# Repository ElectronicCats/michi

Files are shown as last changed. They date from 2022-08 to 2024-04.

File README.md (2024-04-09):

# Michi

<a href="https://electroniccats.com/store/michi/">
  
</a>

<a href="https://github.com/ElectronicCats/michi/wiki">
  
</a>
</p>

  Michi is an electronic board designed by Electronic Cats that simulates configurable keyboard and mouse keys. It has the feature of being able to connect to any conductive material, turning these objects into touch panels. 

  It is an experiment kit for beginners and experts looking to interact between the real world and technology. The Michi can cover the areas of plastic arts, visual arts, music, sports, engineering and even physical rehabilitation.

## For whom is Michi? 

  People 6 years and older, educators, artists, engineers, designers, inventors and creators. 

## How does it work?

  The Michi uses high resistance switching to detect when it has made a connection even with materials that are not very conductive (such as leaves, pasta or people). This technique attracts, Michi can also act as a keyboard or mouse. There are 10 inputs on the front of the board, which can be linked via alligator wires or any other method you can think of. There are another 5 inputs on the back, 3 for keyboard keys and 2 for mouse movement, which can be accessed with jumpers.

  For example, when you connect and touch an apple, you make a connection, and Michi sends the computer a keyboard message. The computer sees Michi as an ordinary keyboard (or mouse). Therefore, it works with all programs, operating systems and web pages, since all programs and web pages receive information from the keyboard and mouse.

## What materials work with Michi?

  Any material that can conduct a little electricity will work. Here are some materials that people have used in our workshops: Ketchup or tomato sauce, Pencil Graphite, Finger Paint, Lemons, etc.

  Other materials that work very well: plants, coins, silverware, anything wet, most foods, aluminum foil, water, and hundreds of things we haven't tried.

## What can I do?

  That's up to you! First, load a computer program or any web page. Let's say you load a piano. Then, instead of using the buttons on the computer keyboard to play the piano, you can connect Michi to something fun, like bananas, and the bananas become your piano keys. 

  Or let's say you search for a Pacman game online and draw a joystick with a pencil. Then you can play Pacman by touching the drawing. 
  The kit includes everything you need: Michi Board, alligator cable, USB cable.

## Manual

Visit our Wiki where you can find the manual 📖: [Wiki](https://github.com/ElectronicCats/michi/wiki)

michi-removebg-preview (https://github.com/ElectronicCats/michi/wiki)

## How to contribute 
 Contributions are welcome! 

Please read the document  [**Contribution Manual**](https://github.com/ElectronicCats/electroniccats-cla/blob/main/electroniccats-contribution-manual.md)  which will show you how to contribute your changes to the project.

✨ Thanks to all our [contributors](https://github.com/ElectronicCats/michi/graphs/contributors)! ✨

See  [**_Electronic Cats CLA_**](https://github.com/ElectronicCats/electroniccats-cla/blob/main/electroniccats-cla.md) for more information.

See the [**community code of conduct**](https://github.com/ElectronicCats/electroniccats-cla/blob/main/electroniccats-community-code-of-conduct.md)   for a vision of the community we want to build and what we expect from it.

### Maintainer

Electronic Cats invests time and resources in providing this open-source design design, please support Electronic Cats and open-source hardware by purchasing products from Electronic Cats!

<a href="https://github.com/sponsors/ElectronicCats">
  
</a>

## Licence

Firmware released under an GNU AGPL v3.0 license. See the [LICENSE](https://www.gnu.org/licenses/agpl-3.0.en.html) file for more information.

Hardware released under an CERN Open Hardware Licence v1.2. See the [LICENSE_HARDWARE](https://ohwr.org/project/licences/wikis/cern-ohl-v1.2) file for more information.

Electronic Cats is a registered trademark, please do not use if you sell these PCBs.

Electronic Cats invests time and resources providing this open source design, please support Electronic Cats and open-source hardware by purchasing products from Electronic Cats!

Designed by Electronic Cats.

30 Jul 2022

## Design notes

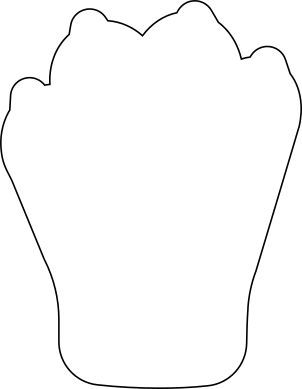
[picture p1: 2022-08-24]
Art/PCB_Michi_Act.png

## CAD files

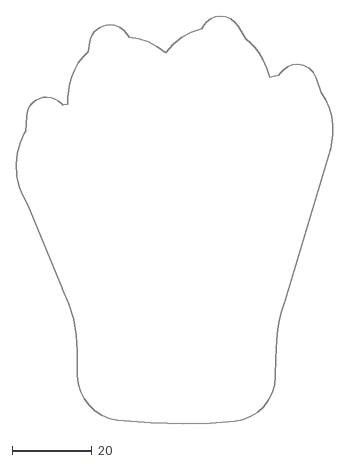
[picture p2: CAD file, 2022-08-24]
Art/PCB_Michi_Act.dxf
79.5 x 102.4

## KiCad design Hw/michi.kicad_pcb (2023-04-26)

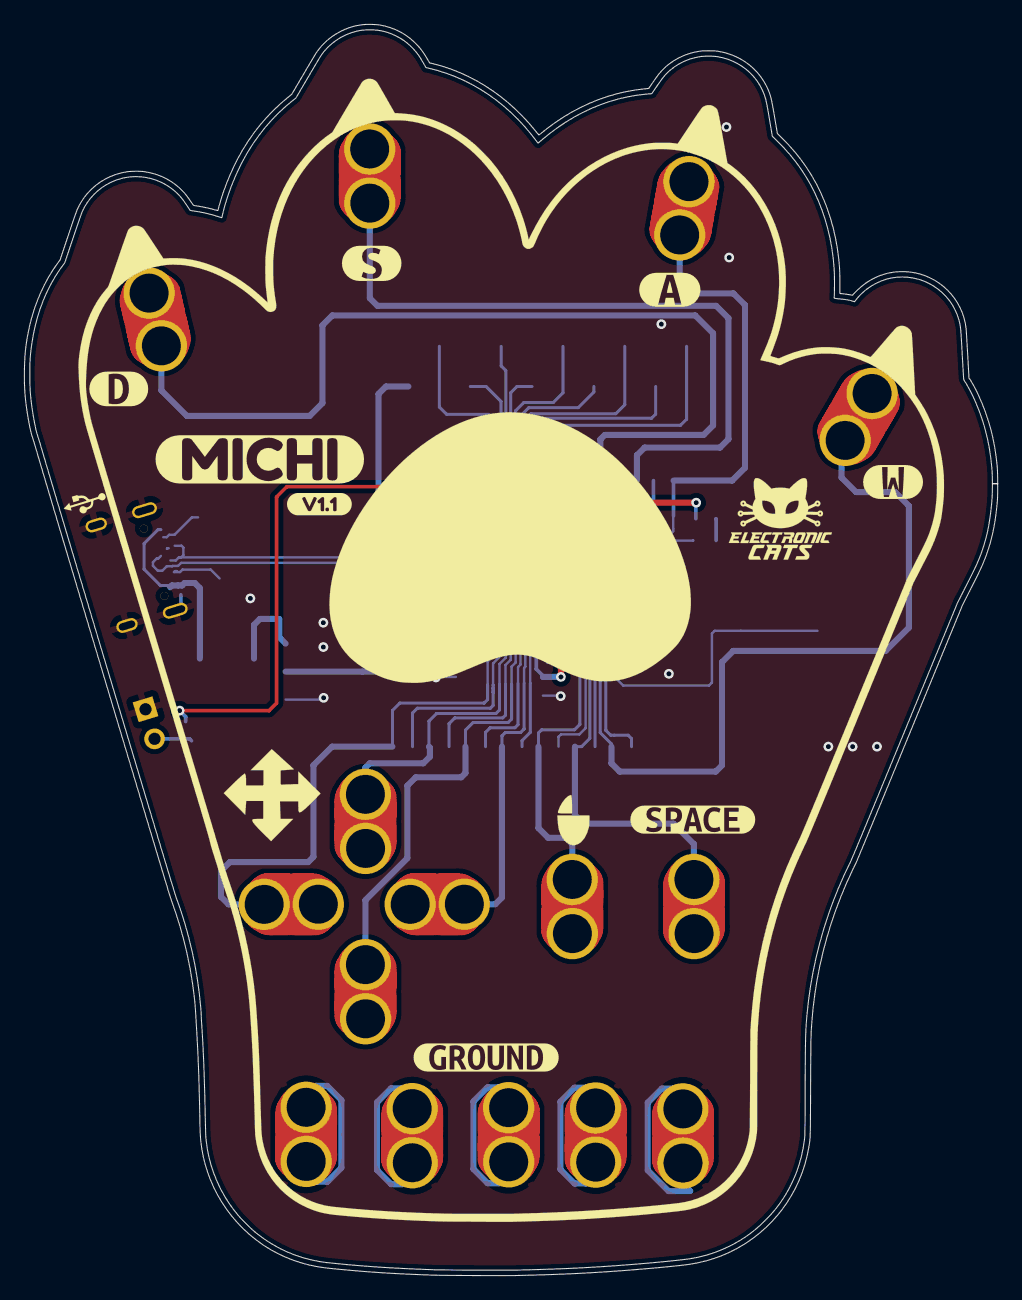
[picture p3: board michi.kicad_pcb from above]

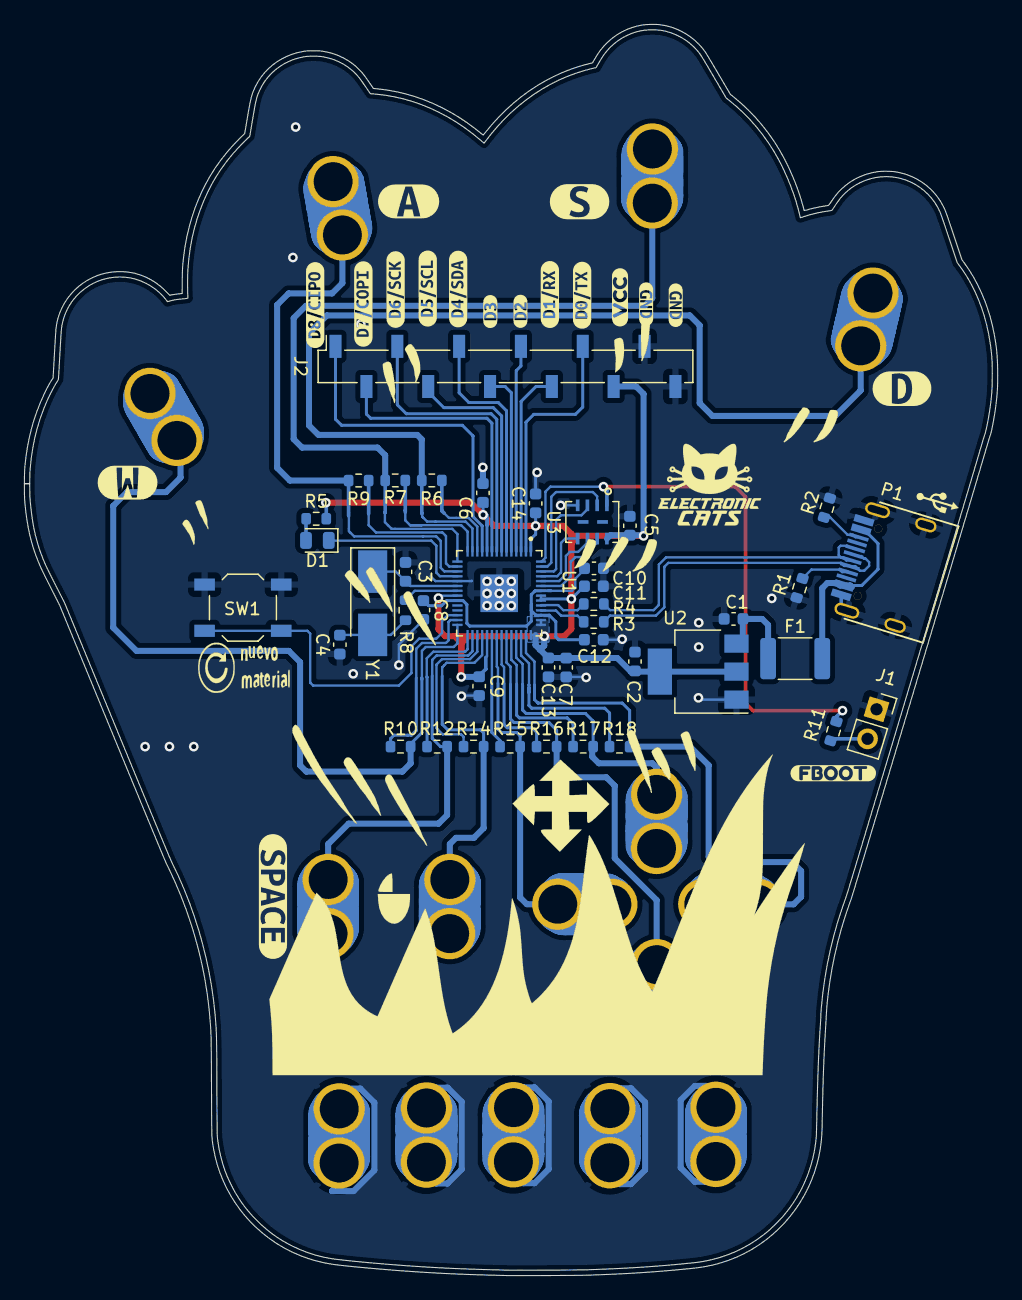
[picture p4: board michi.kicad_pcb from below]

Board: 2 copper layers, 80.0 x 102.8 mm, 85 parts (61 on the bottom side), 53 nets.

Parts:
C1, C2: 10uf; C_0603_1608Metric
C3, C4: 27pf; C_0603_1608Metric
C5, C7, C9, C10, C11, C12, C13, C14: .1uf; C_0603_1608Metric
C6, C8: 1uf; C_0603_1608Metric
D1: LED; D_0805_2012Metric
F1: 0.5A; Fuse_1812_4532Metric_Pad1.30x3.40mm_HandSolder
J1: Conn_01x02; PinSocket_1x02_P2.54mm_Vertical
J2: Conn_Right; PinSocket_1x12_P2.54mm_Vertical_SMD_Pin1Right
P1: USB_C_Plug_USB2.0; C393939
P6, P6#2, P6#3, P6#4, P6#5, P6#6, P6#7, P6#8, P6#9, P6#10, P6#11, P6#12, P6#13, P6#14, P6#15: D; SEWALLI_renew
R1, R2: 5.1K; R_0603_1608Metric
R3, R4: 27.4; R_0603_1608Metric
R5, R8, R11: 1k; R_0603_1608Metric
R6, R7, R9, R10, R12, R14, R15, R16, R17, R18: 22M; R_0603_1608Metric
Ref**: Val**; PCB_Michi_Act
SW1: SW_Push; SW_SPST_TL3342
U1: RP2040; QFN40P700X700X90-57N
U2: NCP1117ST33T3G; SOT-223-3_TabPin2
U3: W25Q128JVS; W25Q16JVUUIQ
Y1: Crystal; Crystal_SMD_5032-2Pin_5.0x3.2mm_HandSoldering
kibuzzard-63055E6D, kibuzzard-63055E6D#2: G***; kibuzzard-63055E6D
kibuzzard-63055E8E, kibuzzard-63055E8E#2: G***; kibuzzard-63055E8E
kibuzzard-63055E62, kibuzzard-63055E62#2: G***; kibuzzard-63055E62
kibuzzard-63055EA5, kibuzzard-63055EA5#2: G***; kibuzzard-63055EA5
kibuzzard-63055F28: G***; kibuzzard-63055F28
kibuzzard-63055FE6, kibuzzard-63055FE6#2: G***; kibuzzard-63055FE6
kibuzzard-630561F0: G***; kibuzzard-630561F0
kibuzzard-630562A3, kibuzzard-630562A3#2: G***; kibuzzard-630562A3
kibuzzard-630562BF: G***; kibuzzard-630562BF
kibuzzard-639765AD: G***; kibuzzard-639765AD
kibuzzard-639765C9: G***; kibuzzard-639765C9
kibuzzard-6305622D: G***; kibuzzard-6305622D
kibuzzard-6305624B: G***; kibuzzard-6305624B
kibuzzard-6305640E: G***; kibuzzard-6305640E
kibuzzard-6449595B: G***; kibuzzard-6449595B
kibuzzard-63056210: G***; kibuzzard-63056210
kibuzzard-63056260: G***; kibuzzard-63056260
kibuzzard-63056270: G***; kibuzzard-63056270
kibuzzard-63056280: G***; kibuzzard-63056280
kibuzzard-63056299: G***; kibuzzard-63056299
svg2mod, svg2mod#2: G***; usb_graphic

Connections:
+1V1: C8.1, C10.1, C12.1, U1.23 (DVDD), U1.45 (VREG_VOUT), U1.50 (DVDD)
+3V3: C2.1, C5.1, C6.1, C7.1, C9.1, C11.1, C13.1, C14.1, J2.10, R5.2, U1.1 (IOVDD), U1.10 (IOVDD), U1.22 (IOVDD), U1.33 (IOVDD), U1.42 (IOVDD), U1.43 (ADC_AVDD), U1.44 (VREG_VIN), U1.48 (USB_VDD), U1.49 (IOVDD), U2.2 (VO), U3.8 (VCC)
/D+: P1.A6 (D+), R4.2
/D-: P1.A7 (D-), R3.2
/DR+: R4.1, U1.47 (USB_DP)
/DR-: R3.1, U1.46 (USB_DM)
/IO0: J2.9, U1.2 (GPIO0)
/IO1: J2.8, U1.3 (GPIO1)
/IO2: J2.7, U1.4 (GPIO2)
/IO3: J2.6, U1.5 (GPIO3)
/IO4: J2.5, U1.6 (GPIO4)
/IO5: J2.4, U1.7 (GPIO5)
/IO6: J2.3, U1.8 (GPIO6)
/IO7: J2.2, U1.9 (GPIO7)
/IO8: J2.1, U1.11 (GPIO8)
/IO9: R6.2, U1.12 (GPIO9)
/IO10: P6#10.1, R6.1, U1.13 (GPIO10)
/IO11: R7.2, U1.14 (GPIO11)
/IO12: P6#12.1, R7.1, U1.15 (GPIO12)
/IO13: R9.2, U1.16 (GPIO13)
/IO14: P6.1, R9.1, U1.17 (GPIO14)
/IO15: D1.1 (K), U1.18 (GPIO15)
/IO16: R10.2, U1.27 (GPIO16)
/IO17: P6#11.1, R10.1, U1.28 (GPIO17)
/IO18: R12.2, U1.29 (GPIO18)
/IO19: P6#15.1, R12.1, U1.30 (GPIO19)
/IO20: R14.2, U1.31 (GPIO20)
/IO21: P6#8.1, R14.1, U1.32 (GPIO21)
/IO22: R15.2, U1.34 (GPIO22)
/IO23: P6#6.1, R15.1, U1.35 (GPIO23)
/IO24: R16.2, U1.36 (GPIO24)
/IO25: P6#2.1, R16.1, U1.37 (GPIO25)
/IO26: R17.2, U1.38 (GPIO26/ADC0)
/IO27: P6#3.1, R17.1, U1.39 (GPIO27/ADC1)
/IO28: R18.2, U1.40 (GPIO28/ADC2)
/IO29: P6#7.1, R18.1, U1.41 (GPIO29/ADC3)
/RST: SW1.1, U1.26 (RUN)
/SCLK: U1.52 (QSPI_SCLK), U3.6 (CLK)
/SD1: U1.55 (QSPI_SD1), U3.2 (DO(IO1))
/SD2: U1.54 (QSPI_SD2), U3.3 (IO2)
/SD3: U1.51 (QSPI_SD3), U3.7 (IO3)
/SDO: U1.53 (QSPI_SD0), U3.5 (DI(IO0))
/SS: R11.2, U1.56 (QSPI_CSN), U3.1 (~CS)
/XIN: C3.2, U1.20 (XIN), Y1.1
/XOUT: R8.1, U1.21 (XOUT)
GND: C1.2, C2.2, C3.1, C4.1, C5.2, C6.2, C7.2, C8.2, C9.2, C10.2, C11.2, C12.2, C13.2, C14.2, J1.1, J2.11, J2.12, P1.A1 (GND), P1.S1 (SHIELD), P6#4.1, P6#5.1, P6#9.1, P6#13.1, P6#14.1, R1.2, R2.2, SW1.2, U1.19 (TESTEN), U1.57 (GND), U2.1 (GND), U3.4 (GND)
unnamed: C4.2, R8.2, Y1.2
unnamed: D1.2 (A), R5.1
unnamed: F1.2, P1.A4 (VBUS)
unnamed: J1.2, R11.1
unnamed: P1.A5 (CC), R1.1
unnamed: P1.B5 (VCONN), R2.1
VBUS: C1.1, F1.1, U2.3 (VI)

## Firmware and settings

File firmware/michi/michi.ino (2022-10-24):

/*
 /////////////////////////////////////////////////
 /////////////HOW TO EDIT THE KEYS ///////////////
 /////////////////////////////////////////////////
 - Edit keys in the settings.h file
 - that file should be open in a tab above (in Arduino IDE)
 - more instructions are in that file
 
 //////////////////////////////////////////////////
 ///////// MICHI FIRMWARE v1.0.0 ////////////
 //////////////////////////////////////////////////


 /************************************************************
Michi - Using the Michi you can make anything into a key 
just by connecting a few alligator clips

Andres Sabas @ Electronic Cats
Original Creation Date: Sept 6, 2022
https://github.com/ElectronicCats/MeowMeow

This example demonstrates how to use Meow Meow

Development environment specifics:
  IDE: Arduino 1.8.19
  Hardware Platform:
  Michi
  - RP2040

This code is beerware; if you see me (or any other Electronic Cats 
member) at the local, and you've found our code helpful, 
please buy us a round!

Distributed as-is; no warranty is given.

Based in the work by:
 by: Eric Rosenbaum, Jay Silver, and Jim Lindblom
 MIT Media Lab & Sparkfun
 start date: 2/16/2012 
 release: 7/5/2012
 ***************************************************************************/

/////////////////////////
// DEBUG DEFINITIONS ////               
/////////////////////////
//#define DEBUG
//#define DEBUG2 
//#define DEBUG3 
//#define DEBUG_TIMING
//#define DEBUG_MOUSE
//#define DEBUG_TIMING2

////////////////////////
// DEFINED CONSTANTS////
////////////////////////

#define BUFFER_LENGTH    3     // 3 bytes gives us 24 samples
#define NUM_INPUTS       10    // 6 on the front + 12 on the back
#define NUM_OUTPUTS       10    //
//#define TARGET_LOOP_TIME 694   // (1/60 seconds) / 24 samples = 694 microseconds per sample 
//#define TARGET_LOOP_TIME 758  // (1/55 seconds) / 24 samples = 758 microseconds per sample 
#define TARGET_LOOP_TIME 744  // (1/56 seconds) / 24 samples = 744 microseconds per sample 

// id numbers for mouse movement inputs (used in settings.h)
#define MOUSE_MOVE_UP       -1 
#define MOUSE_MOVE_DOWN     -2
#define MOUSE_MOVE_LEFT     -3
#define MOUSE_MOVE_RIGHT    -4

#include <Keyboard.h>
#include <Mouse.h>
#include "settings.h"

/////////////////////////
// STRUCT ///////////////
/////////////////////////
typedef struct {
  byte pinNumber;
  int keyCode;
  byte measurementBuffer[BUFFER_LENGTH]; 
  boolean oldestMeasurement;
  byte bufferSum;
  boolean pressed;
  boolean prevPressed;
  boolean isMouseMotion;
  boolean isMouseButton;
  boolean isKey;
} 
MakeyMakeyInput;

MakeyMakeyInput inputs[NUM_INPUTS];

///////////////////////////////////
// VARIABLES //////////////////////
///////////////////////////////////
int bufferIndex = 0;
byte byteCounter = 0;
byte bitCounter = 0;
int mouseMovementCounter = 0; // for sending mouse movement events at a slower interval

int pressThreshold;
int releaseThreshold;
boolean inputChanged;

int mouseHoldCount[NUM_INPUTS]; // used to store mouse movement hold data

// Pin Numbers
// input pin numbers for kickstarter production board
int pinNumbers[NUM_INPUTS] = {
  27, 25, 29, 23, 19, 21,     // top of makey makey board
  17, 14, 12, 10        // left side of female header, KEYBOARD
     // right side of female header, MOUSE
};

int pinNumbers2[NUM_OUTPUTS] = {
  9, 11, 13, 16, 18, 20,     // top of makey makey board
  22, 24, 26, 28        // left side of female header, KEYBOARD
     // right side of female header, MOUSE
};

// input status LED pin numbers
const int inputLED_a = 15;
const int inputLED_b = 8;
const int inputLED_c = 7;
const int outputK = 0;
const int outputM = 1;
byte ledCycleCounter = 0;

// timing
int loopTime = 0;
int prevTime = 0;
int loopCounter = 0;


///////////////////////////
// FUNCTIONS //////////////
///////////////////////////
void initializeArduino();
void initializeInputs();
void updateMeasurementBuffers();
void updateBufferSums();
void updateBufferIndex();
void updateInputStates();
void sendMouseButtonEvents();
void sendMouseMovementEvents();
void addDelay();
void cycleLEDs();
void danceLeds();
void updateOutLEDs();

//////////////////////
// SETUP /////////////
//////////////////////
void setup() 
{
  initializeArduino();
  initializeInputs();
  danceLeds();
}

////////////////////
// MAIN LOOP ///////
////////////////////
void loop() 
{
  updateMeasurementBuffers();
  updateBufferSums();
  updateBufferIndex();
  updateInputStates();
  sendMouseButtonEvents();
  sendMouseMovementEvents();
  cycleLEDs();
  updateOutLEDs();
  addDelay();
}

//////////////////////////
// INITIALIZE ARDUINO
//////////////////////////
void initializeArduino() {
#ifdef DEBUG
  Serial.begin(9600);  // Serial for debugging
#endif

  /* Set up input pins 
   DEactivate the internal pull-ups, since we're using external resistors */
  for (int i=0; i<NUM_INPUTS; i++)
  {
    pinMode(pinNumbers[i], INPUT);
    digitalWrite(pinNumbers[i], LOW);
  }

  for (int i=0; i<NUM_OUTPUTS; i++)
  {
    pinMode(pinNumbers2[i], OUTPUT);
    digitalWrite(pinNumbers2[i], HIGH);
  }

  pinMode(inputLED_a, INPUT);
  pinMode(inputLED_b, INPUT);
  pinMode(inputLED_c, INPUT);
  digitalWrite(inputLED_a, LOW);
  digitalWrite(inputLED_b, LOW);
  digitalWrite(inputLED_c, LOW);

  pinMode(outputK, OUTPUT);
  pinMode(outputM, OUTPUT);
  digitalWrite(outputK, LOW);
  digitalWrite(outputM, LOW);


#ifdef DEBUG
  delay(4000); // allow us time to reprogram in case things are freaking out
#endif

  Keyboard.begin();
  Mouse.begin();
}

///////////////////////////
// INITIALIZE INPUTS
///////////////////////////
void initializeInputs() {

  float thresholdPerc = SWITCH_THRESHOLD_OFFSET_PERC;
  float thresholdCenterBias = SWITCH_THRESHOLD_CENTER_BIAS/50.0;
  float pressThresholdAmount = (BUFFER_LENGTH * 8) * (thresholdPerc / 100.0);
  float thresholdCenter = ( (BUFFER_LENGTH * 8) / 2.0 ) * (thresholdCenterBias);
  pressThreshold = int(thresholdCenter + pressThresholdAmount);
  releaseThreshold = int(thresholdCenter - pressThresholdAmount);

#ifdef DEBUG
  Serial.println(pressThreshold);
  Serial.println(releaseThreshold);
#endif

  for (int i=0; i<NUM_INPUTS; i++) {
    inputs[i].pinNumber = pinNumbers[i];
    inputs[i].keyCode = keyCodes[i];

    for (int j=0; j<BUFFER_LENGTH; j++) {
      inputs[i].measurementBuffer[j] = 0;
    }
    inputs[i].oldestMeasurement = 0;
    inputs[i].bufferSum = 0;

    inputs[i].pressed = false;
    inputs[i].prevPressed = false;

    inputs[i].isMouseMotion = false;
    inputs[i].isMouseButton = false;
    inputs[i].isKey = false;

    if (inputs[i].keyCode < 0) {
#ifdef DEBUG_MOUSE
      Serial.println("GOT IT");  
#endif

      inputs[i].isMouseMotion = true;
    } 
    else if ((inputs[i].keyCode == MOUSE_LEFT) || (inputs[i].keyCode == MOUSE_RIGHT)) {
      inputs[i].isMouseButton = true;
    } 
    else {
      inputs[i].isKey = true;
    }
#ifdef DEBUG
    Serial.println(i);
#endif

  }
}


//////////////////////////////
// UPDATE MEASUREMENT BUFFERS
//////////////////////////////
void updateMeasurementBuffers() {

  for (int i=0; i<NUM_INPUTS; i++) {

    // store the oldest measurement, which is the one at the current index,
    // before we update it to the new one 
    // we use oldest measurement in updateBufferSums
    byte currentByte = inputs[i].measurementBuffer[byteCounter];
    inputs[i].oldestMeasurement = (currentByte >> bitCounter) & 0x01; 

    // make the new measurement
    boolean newMeasurement = digitalRead(inputs[i].pinNumber);

    // invert so that true means the switch is closed
    newMeasurement = !newMeasurement; 

    // store it    
    if (newMeasurement) {
      currentByte |= (1<<bitCounter);
    } 
    else {
      currentByte &= ~(1<<bitCounter);
    }
    inputs[i].measurementBuffer[byteCounter] = currentByte;
  }
}

///////////////////////////
// UPDATE BUFFER SUMS
///////////////////////////
void updateBufferSums() {

  // the bufferSum is a running tally of the entire measurementBuffer
  // add the new measurement and subtract the old one

  for (int i=0; i<NUM_INPUTS; i++) {
    byte currentByte = inputs[i].measurementBuffer[byteCounter];
    boolean currentMeasurement = (currentByte >> bitCounter) & 0x01; 
    if (currentMeasurement) {
      inputs[i].bufferSum++;
    }
    if (inputs[i].oldestMeasurement) {
      inputs[i].bufferSum--;
    }
  }  
}

///////////////////////////
// UPDATE BUFFER INDEX
///////////////////////////
void updateBufferIndex() {
  bitCounter++;
  if (bitCounter == 8) {
    bitCounter = 0;
    byteCounter++;
    if (byteCounter == BUFFER_LENGTH) {
      byteCounter = 0;
    }
  }
}

///////////////////////////
// UPDATE INPUT STATES
///////////////////////////
void updateInputStates() {
  inputChanged = false;
  for (int i=0; i<NUM_INPUTS; i++) {
    inputs[i].prevPressed = inputs[i].pressed; // store previous pressed state (only used for mouse buttons)
    if (inputs[i].pressed) {
      if (inputs[i].bufferSum < releaseThreshold) {  
        inputChanged = true;
        inputs[i].pressed = false;
        if (inputs[i].isKey) {
          Keyboard.release(inputs[i].keyCode);
        }
        if (inputs[i].isMouseMotion) {  
          mouseHoldCount[i] = 0;  // input becomes released, reset mouse hold
        }
      }
      else if (inputs[i].isMouseMotion) {  
        mouseHoldCount[i]++; // input remains pressed, increment mouse hold
      }
    } 
    else if (!inputs[i].pressed) {
      if (inputs[i].bufferSum > pressThreshold) {  // input becomes pressed
        inputChanged = true;
        inputs[i].pressed = true; 
        if (inputs[i].isKey) {
          Keyboard.press(inputs[i].keyCode);
        }
      }
    }
  }
#ifdef DEBUG3
  if (inputChanged) {
    Serial.println("change");
  }
#endif
}

/*
///////////////////////////
 // SEND KEY EVENTS (obsolete, used in versions with pro micro bootloader)
 ///////////////////////////
 void sendKeyEvents() {
 if (inputChanged) {
 KeyReport report = {
 0                                                        };
 for (int i=0; i<6; i++) {
 report.keys[i] = 0;
 } 
 int count = 0;
 for (int i=0; i<NUM_INPUTS; i++) {
 if (inputs[i].pressed && (count < 6)) {
 report.keys[count] = inputs[i].keyCode;
 
 #ifdef DEBUG3
 Serial.println(report.keys[count]);
 #endif
 
 count++;        
 }
 }
 if (count > 0) {
 report.modifiers = 0x00;
 report.reserved = 1;
 Keyboard.sendReport(&report);
 } 
 else {
 report.modifiers = 0x00;
 report.reserved = 0;
 Keyboard.sendReport(&report);
 }      
 } 
 else {
 // might need a delay here to compensate for the time it takes to send keyreport
 }
 }
 */

/////////////////////////////
// SEND MOUSE BUTTON EVENTS 
/////////////////////////////
void sendMouseButtonEvents() {
  if (inputChanged) {
    for (int i=0; i<NUM_INPUTS; i++) {
      if (inputs[i].isMouseButton) {
        if (inputs[i].pressed) {
          if (inputs[i].keyCode == MOUSE_LEFT) {
            Mouse.press(MOUSE_LEFT);
          } 
          if (inputs[i].keyCode == MOUSE_RIGHT) {
            Mouse.press(MOUSE_RIGHT);
          } 
        } 
        else if (inputs[i].prevPressed) {
          if (inputs[i].keyCode == MOUSE_LEFT) {
            Mouse.release(MOUSE_LEFT);
          } 
          if (inputs[i].keyCode == MOUSE_RIGHT) {
            Mouse.release(MOUSE_RIGHT);
          }           
        }
      }
    }
  }
}

//////////////////////////////
// SEND MOUSE MOVEMENT EVENTS
//////////////////////////////
void sendMouseMovementEvents() {
  byte right = 0;
  byte left = 0;
  byte down = 0;
  byte up = 0;
  int horizmotion = 0;
  int vertmotion = 0;

  mouseMovementCounter++;
  mouseMovementCounter %= MOUSE_MOTION_UPDATE_INTERVAL;
  if (mouseMovementCounter == 0) {
    for (int i=0; i<NUM_INPUTS; i++) {
#ifdef DEBUG_MOUSE
      //  Serial.println(inputs[i].isMouseMotion);  
#endif

      if (inputs[i].isMouseMotion) {
        if (inputs[i].pressed) {
          if (inputs[i].keyCode == MOUSE_MOVE_UP) {
            // JL Changes (x4): now update to 1 + a hold factor, constrained between 1 and mouse max movement speed
            up=constrain(1+mouseHoldCount[i]/MOUSE_RAMP_SCALE, 1, MOUSE_MAX_PIXELS);
          }  
          if (inputs[i].keyCode == MOUSE_MOVE_DOWN) {
            down=constrain(1+mouseHoldCount[i]/MOUSE_RAMP_SCALE, 1, MOUSE_MAX_PIXELS);
          }  
          if (inputs[i].keyCode == MOUSE_MOVE_LEFT) {
            left=constrain(1+mouseHoldCount[i]/MOUSE_RAMP_SCALE, 1, MOUSE_MAX_PIXELS);
          }  
          if (inputs[i].keyCode == MOUSE_MOVE_RIGHT) {
            right=constrain(1+mouseHoldCount[i]/MOUSE_RAMP_SCALE, 1, MOUSE_MAX_PIXELS);
          }  
        }
      }
    }

    // diagonal scrolling and left/right cancellation
    if(left > 0)
    {
      if(right > 0)
      {
        horizmotion = 0; // cancel horizontal motion because left and right are both pushed
      }
      else
      {
        horizmotion = -left; // left yes, right no
      }
    }
    else
    {
      if(right > 0)
      {
        horizmotion = right; // right yes, left no
      }
    }

    if(down > 0)
    {
      if(up > 0)
      {
        vertmotion = 0; // cancel vertical motion because up and down are both pushed
      }
      else
      {
        vertmotion = down; // down yes, up no
      }
    }
    else
    {
      if (up > 0)
      {
        vertmotion = -up; // up yes, down no
      }
    }
    // now move the mouse
    if( !((horizmotion == 0) && (vertmotion==0)) )
    {
      Mouse.move(horizmotion * PIXELS_PER_MOUSE_STEP, vertmotion * PIXELS_PER_MOUSE_STEP);
    }
  }
}

///////////////////////////
// ADD DELAY
///////////////////////////
void addDelay() {

  loopTime = micros() - prevTime;
  if (loopTime < TARGET_LOOP_TIME) {
    int wait = TARGET_LOOP_TIME - loopTime;
    delayMicroseconds(wait);
  }

  prevTime = micros();

#ifdef DEBUG_TIMING
  if (loopCounter == 0) {
    int t = micros()-prevTime;
    Serial.println(t);
  }
  loopCounter++;
  loopCounter %= 999;
#endif

}

///////////////////////////
// CYCLE LEDS
///////////////////////////
void cycleLEDs() {
  pinMode(inputLED_a, INPUT);
  pinMode(inputLED_b, INPUT);
  pinMode(inputLED_c, INPUT);
  digitalWrite(inputLED_a, LOW);
  digitalWrite(inputLED_b, LOW);
  digitalWrite(inputLED_c, LOW);

  ledCycleCounter++;
  ledCycleCounter %= 6;

  if ((ledCycleCounter == 0) && inputs[0].pressed) {
    pinMode(inputLED_a, INPUT);
    digitalWrite(inputLED_a, LOW);
    pinMode(inputLED_b, OUTPUT);
    digitalWrite(inputLED_b, HIGH);
    pinMode(inputLED_c, OUTPUT);
    digitalWrite(inputLED_c, LOW);
  }
  if ((ledCycleCounter == 1) && inputs[1].pressed) {
    pinMode(inputLED_a, OUTPUT);
    digitalWrite(inputLED_a, HIGH);
    pinMode(inputLED_b, OUTPUT);
    digitalWrite(inputLED_b, LOW);
    pinMode(inputLED_c, INPUT);
    digitalWrite(inputLED_c, LOW);

  }
  if ((ledCycleCounter == 2) && inputs[2].pressed) {
    pinMode(inputLED_a, OUTPUT);
    digitalWrite(inputLED_a, LOW);
    pinMode(inputLED_b, OUTPUT);
    digitalWrite(inputLED_b, HIGH);
    pinMode(inputLED_c, INPUT);
    digitalWrite(inputLED_c, LOW);
  }
  if ((ledCycleCounter == 3) && inputs[3].pressed) {
    pinMode(inputLED_a, INPUT);
    digitalWrite(inputLED_a, LOW);
    pinMode(inputLED_b, OUTPUT);
    digitalWrite(inputLED_b, LOW);
    pinMode(inputLED_c, OUTPUT);
    digitalWrite(inputLED_c, HIGH);
  }
  if ((ledCycleCounter == 4) && inputs[4].pressed) {
    pinMode(inputLED_a, OUTPUT);
    digitalWrite(inputLED_a, LOW);
    pinMode(inputLED_b, INPUT);
    digitalWrite(inputLED_b, LOW);
    pinMode(inputLED_c, OUTPUT);
    digitalWrite(inputLED_c, HIGH);
  }
  if ((ledCycleCounter == 5) && inputs[5].pressed) {
    pinMode(inputLED_a, OUTPUT);
    digitalWrite(inputLED_a, HIGH);
    pinMode(inputLED_b, INPUT);
    digitalWrite(inputLED_b, LOW);
    pinMode(inputLED_c, OUTPUT);
    digitalWrite(inputLED_c, LOW);
  }

}

///////////////////////////
// DANCE LEDS
///////////////////////////
void danceLeds()
{
  int delayTime = 50;
  int delayTime2 = 100;

  // CIRCLE
  for(int i=0; i<4; i++)
  {
    // UP
    pinMode(inputLED_a, INPUT);
    digitalWrite(inputLED_a, LOW);
    pinMode(inputLED_b, OUTPUT);
    digitalWrite(inputLED_b, HIGH);
    pinMode(inputLED_c, OUTPUT);
    digitalWrite(inputLED_c, LOW);
    delay(delayTime);

    //RIGHT
    pinMode(inputLED_a, INPUT);
    digitalWrite(inputLED_a, LOW);
    pinMode(inputLED_b, OUTPUT);
    digitalWrite(inputLED_b, LOW);
    pinMode(inputLED_c, OUTPUT);
    digitalWrite(inputLED_c, HIGH);
    delay(delayTime);


    // DOWN
    pinMode(inputLED_a, OUTPUT);
    digitalWrite(inputLED_a, HIGH);
    pinMode(inputLED_b, OUTPUT);
    digitalWrite(inputLED_b, LOW);
    pinMode(inputLED_c, INPUT);
    digitalWrite(inputLED_c, LOW);
    delay(delayTime);

    // LEFT
    pinMode(inputLED_a, OUTPUT);
    digitalWrite(inputLED_a, LOW);
    pinMode(inputLED_b, OUTPUT);    
    digitalWrite(inputLED_b, HIGH);
    pinMode(inputLED_c, INPUT);
    digitalWrite(inputLED_c, LOW);
    delay(delayTime);    
  }    

  // WIGGLE
  for(int i=0; i<4; i++)
  {
    // SPACE
    pinMode(inputLED_a, OUTPUT);
    digitalWrite(inputLED_a, HIGH);
    pinMode(inputLED_b, INPUT);
    digitalWrite(inputLED_b, LOW);
    pinMode(inputLED_c, OUTPUT);
    digitalWrite(inputLED_c, LOW);
    delay(delayTime2);    

    // CLICK
    pinMode(inputLED_a, OUTPUT);
    digitalWrite(inputLED_a, LOW);
    pinMode(inputLED_b, INPUT);
    digitalWrite(inputLED_b, LOW);
    pinMode(inputLED_c, OUTPUT);
    digitalWrite(inputLED_c, HIGH);
    delay(delayTime2);    
  }
}

void updateOutLEDs()
{
  boolean keyPressed = 0;
  boolean mousePressed = 0;

  for (int i=0; i<NUM_INPUTS; i++)
  {
    if (inputs[i].pressed)
    {
      if (inputs[i].isKey)
      {
        keyPressed = 1;
#ifdef DEBUG
        Serial.print("Key ");
        Serial.print(i);
        Serial.println(" pressed");
#endif
      }
      else
      {
        mousePressed = 1;
      }
    }
  }

  if (keyPressed)
  {
    digitalWrite(outputK, HIGH);
    //TXLED1;
  }
  else
  {
    digitalWrite(outputK, LOW);
    //TXLED0;
  }

  if (mousePressed)
  {
    digitalWrite(outputM, HIGH);
    //RXLED1;
  }
  else
  {
    digitalWrite(outputM, LOW);
    //RXLED0;
  }
}

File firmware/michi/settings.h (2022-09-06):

#include "Arduino.h"

/*
/////////////////////////////////////////////////////////////////////////
// KEY MAPPINGS: WHICH KEY MAPS TO WHICH PIN ON THE Michi BOARD? //
/////////////////////////////////////////////////////////////////////////
  
  - edit the keyCodes array below to change the keys sent by the Michi for each input
  - the comments tell you which input sends that key (for example, by default 'w' is sent by pin D5)
  - change the keys by replacing them. for example, you can replace 'w' with any other individual letter,
    number, or symbol on your keyboard
  - you can also use codes for other keys such as modifier and function keys (see the
    the list of additional key codes at the bottom of this file)

*/

int keyCodes[NUM_INPUTS] = {
  // top side of the michi board
 
  KEY_UP_ARROW,      // up arrow pad
  KEY_DOWN_ARROW,    // down arrow pad
  KEY_LEFT_ARROW,    // left arrow pad
  KEY_RIGHT_ARROW,   // right arrow pad
  ' ',               // space button pad
  MOUSE_LEFT,        // click button pad
  
  // female header on the back left side
  
  'w',                // pin D5
  'a',                // pin D4
  's',                // pin D3
  'd',                // pin D2
};

///////////////////////////
// NOISE CANCELLATION /////
///////////////////////////
#define SWITCH_THRESHOLD_OFFSET_PERC  5    // number between 1 and 49
                                           // larger value protects better against noise oscillations, but makes it harder to press and release
                                           // recommended values are between 2 and 20
                                           // default value is 5

#define SWITCH_THRESHOLD_CENTER_BIAS 55   // number between 1 and 99
                                          // larger value makes it easier to "release" keys, but harder to "press"
                                          // smaller value makes it easier to "press" keys, but harder to "release"
                                          // recommended values are between 30 and 70
                                          // 50 is "middle" 2.5 volt center
                                          // default value is 55
                                          // 100 = 5V (never use this high)
                                          // 0 = 0 V (never use this low
                                          

/////////////////////////
// MOUSE MOTION /////////
/////////////////////////
#define MOUSE_MOTION_UPDATE_INTERVAL  35   // how many loops to wait between 
                                           // sending mouse motion updates
                                           
#define PIXELS_PER_MOUSE_STEP         4     // a larger number will make the mouse
                                           // move faster

#define MOUSE_RAMP_SCALE              150  // Scaling factor for mouse movement ramping
                                           // Lower = more sensitive mouse movement
                                           // Higher = slower ramping of speed
                                           // 0 = Ramping off
                                            
#define MOUSE_MAX_PIXELS              10   // Max pixels per step for mouse movement

/*

///////////////////////////
// ADDITIONAL KEY CODES ///
///////////////////////////

- you can use these codes in the keyCodes array above
- to get modifier keys, function keys, etc 

KEY_LEFT_CTRL
KEY_LEFT_SHIFT		
KEY_LEFT_ALT		
KEY_LEFT_GUI		
KEY_RIGHT_CTRL		
KEY_RIGHT_SHIFT		
KEY_RIGHT_ALT	
KEY_RIGHT_GUI		

KEY_BACKSPACE		
KEY_TAB				
KEY_RETURN			
KEY_ESC				
KEY_INSERT			
KEY_DELETE			
KEY_PAGE_UP			
KEY_PAGE_DOWN		
KEY_HOME
KEY_END				
KEY_CAPS_LOCK	
	
KEY_F1				
KEY_F2				
KEY_F3				
KEY_F4				
KEY_F5				
KEY_F6				
KEY_F7				
KEY_F8				
KEY_F9				
KEY_F10
KEY_F11				
KEY_F12			

*/

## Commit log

2022-06-30 Added project
    [PCB_resistive_sensors.kicad_pcb, PCB_resistive_sensors.kicad_sch]
2022-06-30 Created "Hw" carpet
    [PCB_resistive_sensors.kicad_pcb, PCB_resistive_sensors.kicad_sch]
2022-06-30 anotate changes
    [PCB_resistive_sensors.kicad_sch]
2022-08-15 rename files hardware
    [PCB_resistive_sensors.kicad_pcb, michi.kicad_pcb, michi.kicad_sch]
2022-08-15 Added Art Michi
    [michi.kicad_pcb]
2022-08-19 Floorplan placement
    [michi.kicad_pcb, michi.kicad_sch]
2022-08-22 Started PCB routing
    [michi.kicad_pcb, michi.kicad_sch]
2022-08-22 Fixed PCB outline
    [michi.kicad_pcb]
2022-08-22 Resisitive sensors connected
    [michi.kicad_pcb, michi.kicad_sch]
2022-08-23 Edge.Cuts generated
    [michi.kicad_pcb]
2022-08-23 Reverse footprint
    [michi.kicad_pcb]
2022-08-23 Add labels
    [michi.kicad_pcb]
2022-08-24 fix footprints
    [michi.kicad_pcb, michi.kicad_sch]
2022-08-24 update v1.0 layout
    [PCB_Michi_Act.dxf, michi.kicad_pcb, michi.kicad_sch]
2022-08-30 Update BOM
    [michi.kicad_sch]
2022-09-06 Update labels schematic
    [michi.kicad_sch]
2022-12-12 fix label VCC 3v3
    [michi.kicad_pcb]
2023-04-26 label v1.1
    [michi.kicad_pcb]
2023-10-27 change R3 & R4 #manf for stock
    [michi.kicad_sch]
